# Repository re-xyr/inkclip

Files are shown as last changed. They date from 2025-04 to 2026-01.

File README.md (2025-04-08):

# Inkclip

Inkclip is an e-paper hair clip.

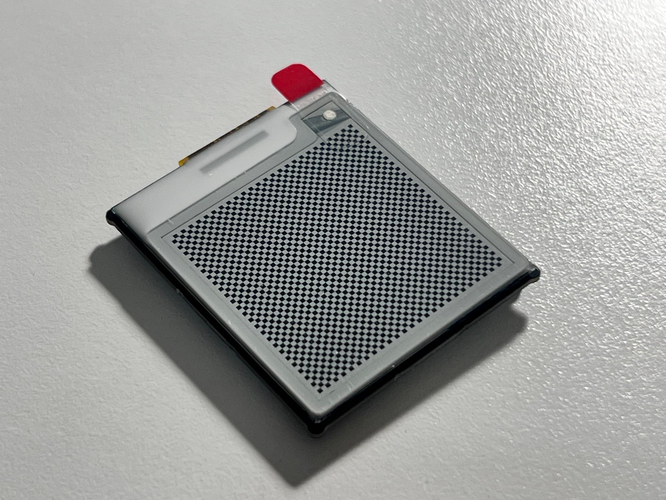
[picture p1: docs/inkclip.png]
An Inkclip lying on a desk.


## Features

- It looks cool, if you are the type of person who thinks this kind of things look cool.
- Use it as more than a hair clip: a pin, a pocket clip, or just a gadget on your desktop.
- Update the pattern on the hair clip by simply connecting it to a computer via USB.
  - There is a ready-made web application you can use for this!
- Everything is open source: the hardware, the firmware, and the webapp.

## Physical characteristics

- Display size: 1.54 inches
- Resolution: 200 x 200 px
- Color: black and white
- Thickness (average): 2.60mm
- Thickness (thickest): 5.00mm (at micro-B port)
- Minimum weight (without mounting hardware): 6.5g
- Typical weight (with a 35mm hair clip): 8.0g
- Size: 33.40mm x 33.92mm
  - The shape of the device is a 32.80mm x 38.32mm rectangle with 1mm-radius dogbone corners.

## Project structure

- `hardware/` is the KiCad project for the Inkclip hardware.
- `firmware/` is a simple firmware for Inkclip that receives image bitmaps and then updates the entire display.
- `webapp/` is a web application for updating the display that works with the aforementioned firmware.

## Demo

A demo of an Inkclip refreshing its display.

## License

The hardware design portion of this project is available under the *CERN Open Hardware Licence Version 2 - Strongly Reciprocal (`CERN-OHL-S-2.0`)* while the software portion is available under the *GNU General Public License v3.0 or later (`GPL-3.0-or-later`)*. For details, refer to the `LICENSE` files under each subdirectory of this repository.

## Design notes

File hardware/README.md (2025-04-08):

# PCB design files of Inkclip

This is the [KiCad](https://www.kicad.org/) project for the PCB design of Inkclip. This PCB is designed to work with [Waveshare's 1.54-inch e-paper](https://www.waveshare.com/product/1.54inch-e-paper.htm).

The shape of the PCB is a 32.80 x 38.32mm rectangle with 1mm-radius dogbone corners. This ensures 0.5mm clearance from the PCB edge to the e-paper everywhere along the edges. Approximately in the middle of the PCB there is a 7.5mm wide horizontal component-free zone where you may attach mounting solutions of your choice (e.g. a hairclip, a pin, a pocket clip, velcro, tape, etc).

Specifically notice that the 24-pin FPC connector must be *top-contact* since the FPC cable of the display module is supposed to bend over so that the display may be mounted on the back side of the PCB. The positioning of this FPC connector is under the assumption that the PCB is 1.0mm thick, which is the thinnest [JLCPCB](https://jlcpcb.com) could print without the price going up. If you plan to print a thinner/thicker PCB then you might need to adjust the position of this connector accordingly.

This design uses an [STM32F411CEU6](https://www.st.com/en/microcontrollers-microprocessors/stm32f411ce.html) MCU. It has 512kB flash and 128kB RAM, which should be significantly more than what is needed by the firmware provided in this repository. On the bottom-right corner of the PCB there are pin holes for SWD debugging in the order [GND, SWCLK, SWDIO, 3V3]. The pushbutton on the PCB pulls BOOT0 up, which brings the MCU into DFU mode where you can write firmware over USB.

## License

The hardware design of Inkclip, namely all files under this directory, is provided under [CERN Open Hardware License Version 2 - Strongly Reciprocal (`CERN-OHL-S-2.0`)](LICENSE).

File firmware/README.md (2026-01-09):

# Inkclip Firmware

> WARNING! Contents below are outdated; we are currently using a USB MIDI-based firmware for better cross-platform compatibility.

This is the firmware implementation for Inkclip. It implements a USB 2.0 HID device with the following reports:

- **Write Pattern:** Report ID = 0x01, Direction = Output (host to device), Size = 5,000 bytes.

  Updates the pattern on the e-paper display of the device. The 5,000 bytes are interpreted as a 40,000-bit bit vector that represents a bitmap of the 200x200 pattern to be displayed. Each byte is the little-endian representation of 8 pixels on the display, from left to right, from top to bottom, in row-major order.

  Namely, the `k`th least significant bit in the `n`th byte of the report represents the pixel value at coordinates `(x, y) = (n % 25 + k, n / 25)`.

- **Serial Number Request:** Report ID = 0x02, Direction = Output (host to device), Size = 1 byte.

  Sends a request for the device's unique serial number. The content of the 1-byte payload is ignored.

- **Serial Number Response:** Report ID = 0x02, Direction = Input (device to host), Size = 16 bytes.

  An ASCII representation of the device's unique serial number. Currently, this is implemented as the base-64 encoding of the 12-byte UID of the STM32 MCU.

## Flashing the Firmware

If you simply want to flash the firmware onto a completed Inkclip device, you can use the [cargo-dfu](https://github.com/dfu-rs/cargo-dfu) tool. Simply connect the device via USB with BOOT0 pulled up and then run under this directory

```sh
cargo dfu --release
```

If you want to debug this firmware through e.g. [SWD](https://developer.arm.com/documentation/100893/latest/Debug-and-trace-interface/Serial-Wire-Debug-signals) then you can use [probe-rs](https://probe.rs/) with a debugging probe instead.

## Implementation Details

- The USB device sets the maximum current to 100mA, which should be well above the active power draw of the actual hardware (9mA MCU + 8mA e-paper).
- The SPI link between the MCU and the e-paper display is 20MHz, which is the maximum supported frequency listed on the display module's datasheet.
- This firmware is implemented in no_std Rust with the [embassy](https://embassy.dev) framework and the [embassy-stm32](https://docs.embassy.dev/embassy-stm32/git/stm32f411ce/index.html) HAL.

## License

This firmware implementation for Inkclip, namely all files under this directory, is provided under [GNU General Public License v3.0 or later (`GPL-3.0-or-later`)](LICENSE).

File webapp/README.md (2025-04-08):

# Write to Inkclip

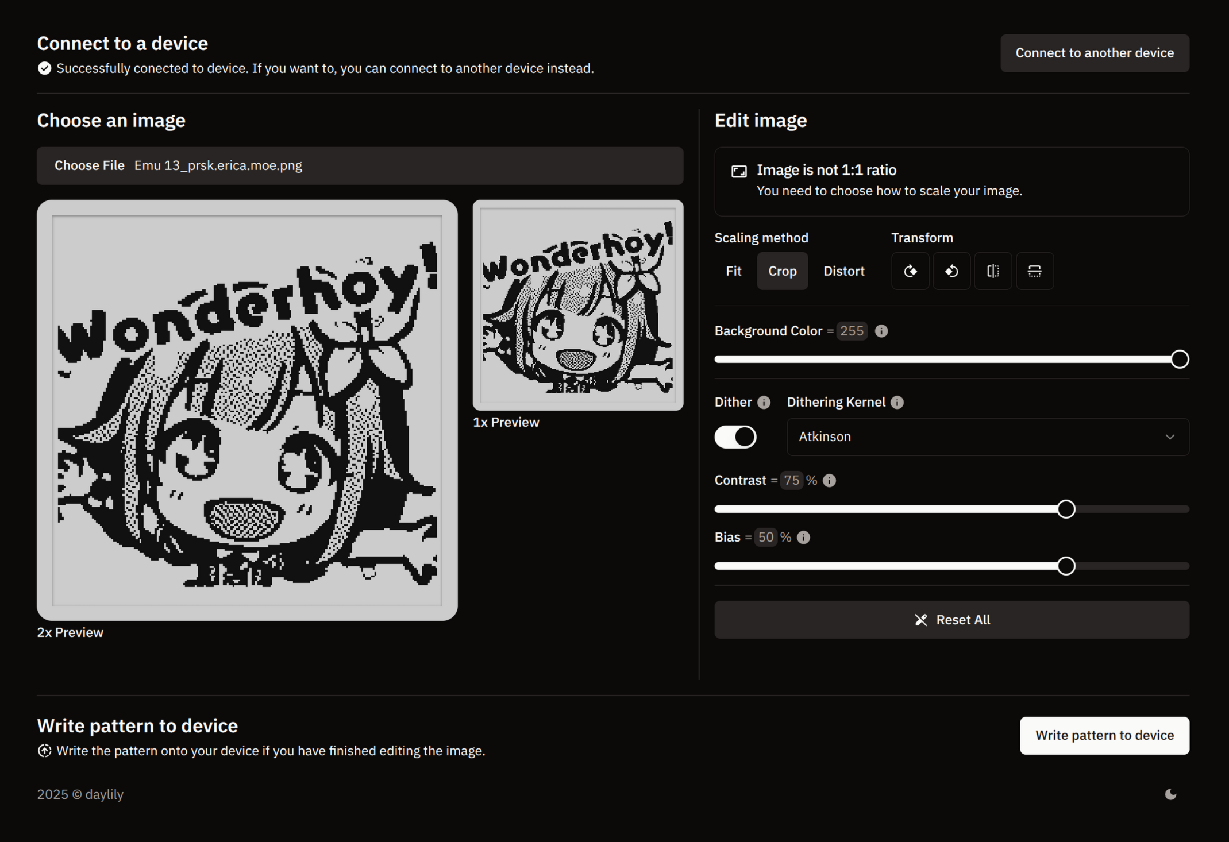
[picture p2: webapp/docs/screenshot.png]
A screenshot of the Write to Inkclip web app.


Write to Inkclip is a web application for writing patterns onto the Inkclip device. It handles the conversion from any raster image format supported by the user's web browser into a format that is understood by the Inkclip firmware, and then sends this data to the connected Inkclip via WebHID.

This application also supports some primitive image editing functions, such as scaling and cropping, rotation and mirroring, the adjustment of contrast and brightness, and a range of dithering algorithms available to use for converting images to black-and-white.

## Building

Run `npm run dev` under this directory in order to spin up a Vite development server, and run `npm run build` to bundle the application.

## Technical matters

Write to Inkclip depends on the [WebHID API](https://developer.mozilla.org/en-US/docs/Web/API/WebHID_API) to send data to devices. As a consequence, it is only supported on Chromium-based browsers, which are the only browsers that support WebHID at this time.

Write to Inkclip is a fully client-side application. It is built with [Svelte](https://svelte.dev), [shadcn-svelte](https://next.shadcn-svelte.com), [Vite](https://vite.dev), and [Tailwind CSS](https://tailwindcss.com). An instance of Write to Inkclip is hosted at https://inkclip.dayli.ly.

## License

The Write to Inkclip web application, namely all files under this directory, is provided under [GNU General Public License v3.0 or later (`GPL-3.0-or-later`)](LICENSE).

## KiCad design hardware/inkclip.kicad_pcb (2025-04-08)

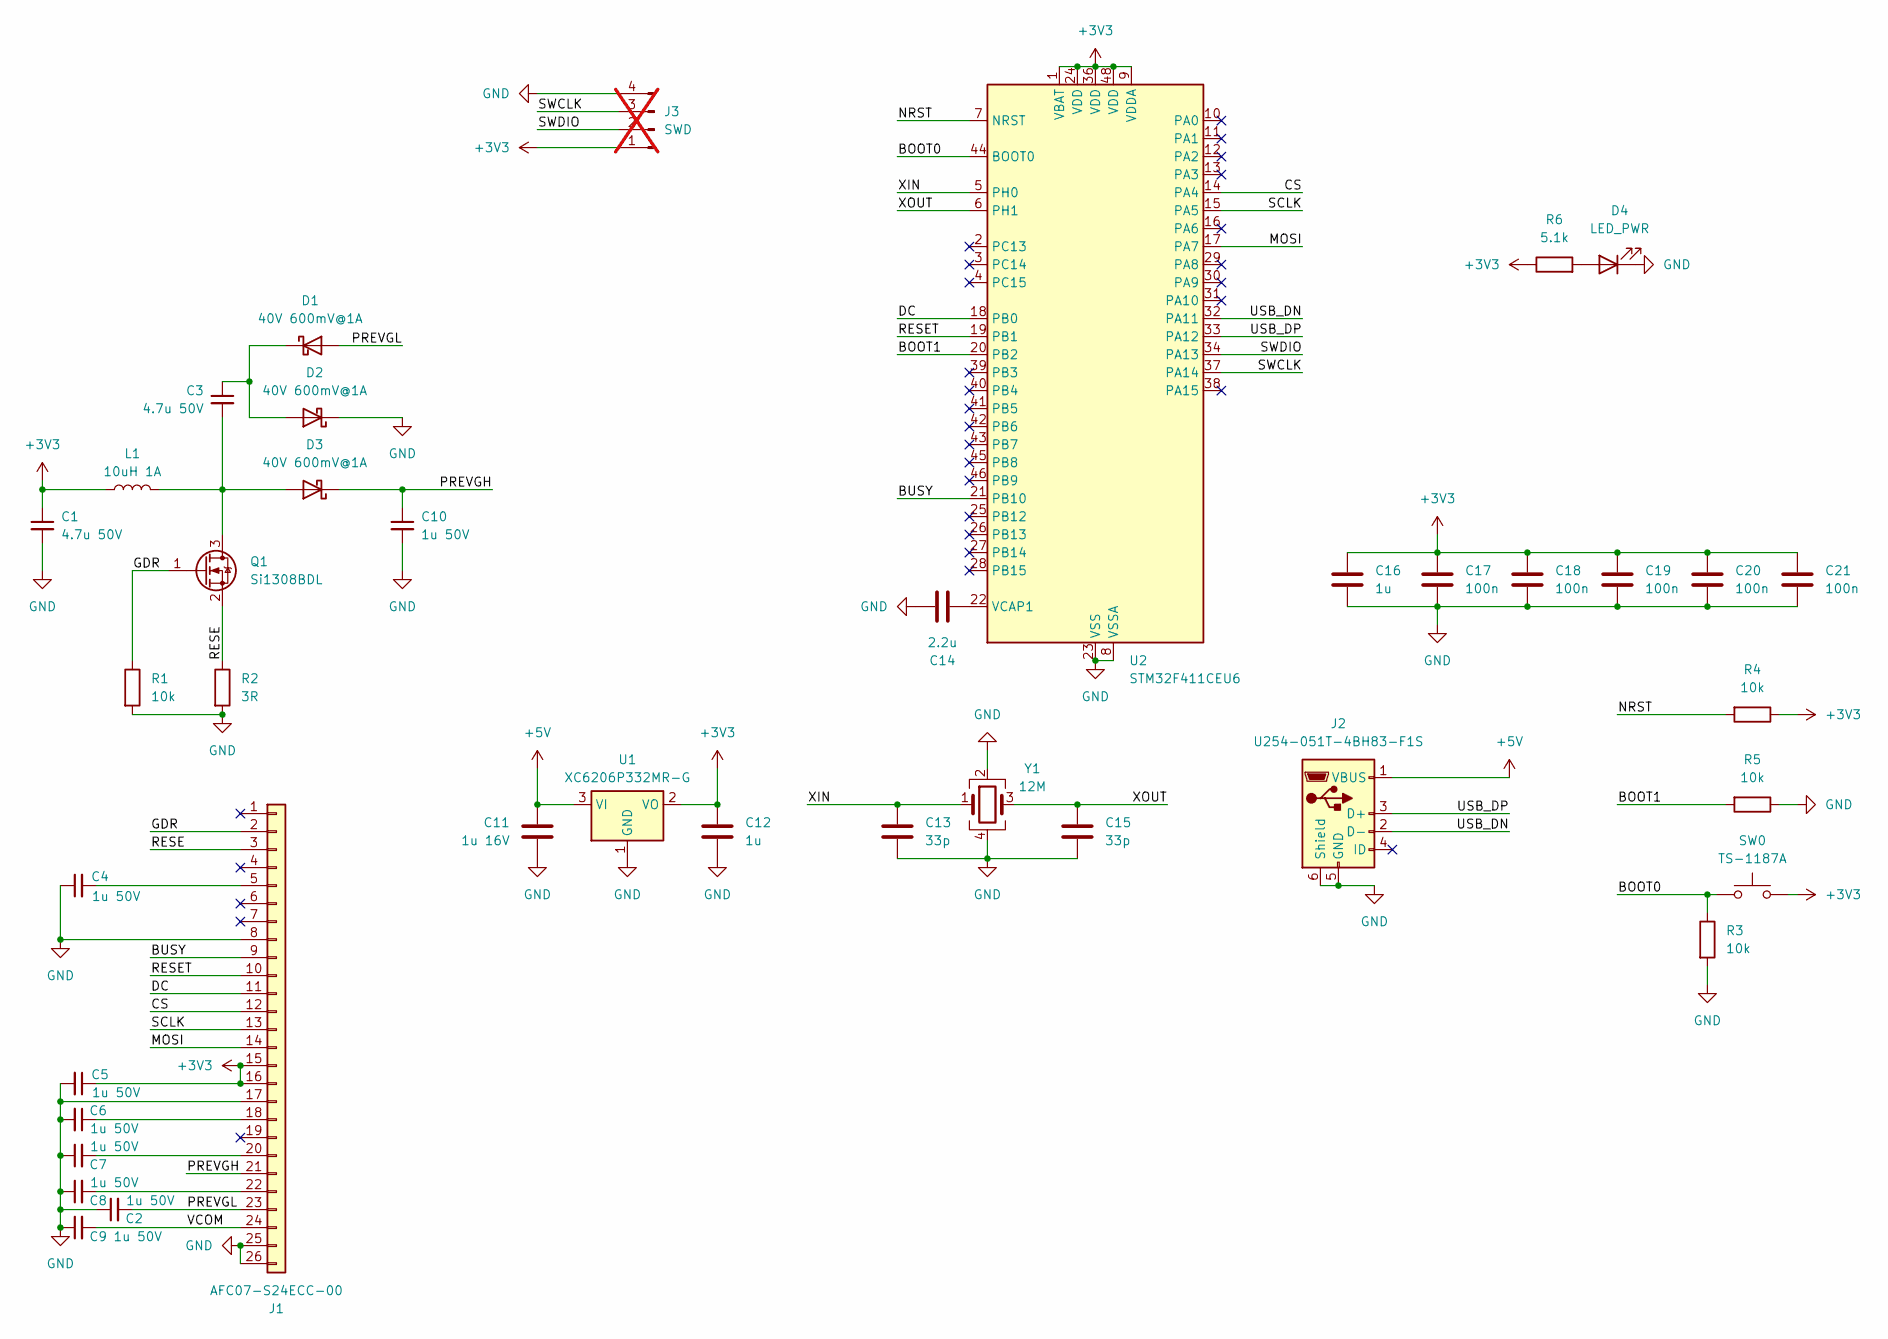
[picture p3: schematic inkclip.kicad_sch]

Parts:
C1, C3: 4.7u 50V; C_1206_3216Metric
C2, C4, C5, C6, C7, C8, C9, C10: 1u 50V; C_0603_1608Metric
C11: 1u 16V; C_0402_1005Metric
C12, C16: 1u; C_0402_1005Metric
C13, C15: 33p; C_0402_1005Metric
C14: 2.2u; C_0402_1005Metric
C17, C18, C19, C20, C21: 100n; C_0402_1005Metric
D1, D2, D3: 40V 600mV@1A; D_SOD-323
D4: LED_PWR; LED_0603_1608Metric
J1: AFC07-S24ECC-00; FPC-SMD_24P-L17.5-W5.4-P0.50
J2: U254-051T-4BH83-F1S; USB_Micro-B_XKB_U254-051T-4BH83-F1S
J3: SWD; PinHeader_1x04_P2.54mm_Vertical; not fitted
L1: 10uH 1A; L_Changjiang_FNR4018S
Q1: Si1308BDL; SOT-323_SC-70
R1, R3, R4, R5: 10k; R_0402_1005Metric
R2: 3R; R_0402_1005Metric
R6: 5.1k; R_0402_1005Metric
SW0: TS-1187A; SW_Push_1P1T_XKB_TS-1187A
U1: XC6206P332MR-G; SOT-23-3
U2: STM32F411CEU6; QFN-48-1EP_7x7mm_P0.5mm_EP5.6x5.6mm
Y1: 12M; Crystal_SMD_3225-4Pin_3.2x2.5mm

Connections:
+3V3: C1.1, C5.1, C12.1, C16.1, C17.1, C18.1, C19.1, C20.1, C21.1, J1.15, J1.16, J3.1, L1.1, R4.1, R6.1, SW0.2, U1.2 (VO), U2.1 (VBAT), U2.9 (VDDA), U2.24 (VDD), U2.36 (VDD), U2.48 (VDD)
+5V: C11.1, J2.1 (VBUS), U1.3 (VI)
/BOOT0: R3.1, SW0.1, U2.44 (BOOT0)
/BOOT1: R5.2, U2.20 (PB2)
/BUSY: J1.9, U2.21 (PB10)
/CS: J1.12, U2.14 (PA4)
/DC: J1.11, U2.18 (PB0)
/GDR: J1.2, Q1.1 (G), R1.1
/LED: U2.25 (PB12)
/MOSI: J1.14, U2.17 (PA7)
/NRST: R4.2, U2.7 (NRST)
/PREVGH: C10.1, D3.1 (K), J1.21
/PREVGL: C2.2, D1.2 (A), J1.23
/RESE: J1.3, Q1.2 (S), R2.1
/RESET: J1.10, U2.19 (PB1)
/SCLK: J1.13, U2.15 (PA5)
/SWCLK: J3.3, U2.37 (PA14)
/SWDIO: J3.2, U2.34 (PA13)
/USB_DN: J2.2 (D-), U2.32 (PA11)
/USB_DP: J2.3 (D+), U2.33 (PA12)
/VCOM: C9.2, J1.24
/XIN: C13.1, U2.5 (PH0), Y1.1
/XOUT: C15.1, U2.6 (PH1), Y1.3
GND: C1.2, C2.1, C4.1, C5.2, C6.2, C7.1, C8.1, C9.1, C10.2, C11.2, C12.2, C13.2, C14.1, C15.2, C16.2, C17.2, C18.2, C19.2, C20.2, C21.2, D2.1 (K), D4.1 (K), J1.8, J1.17, J1.25, J1.26, J2.5 (GND), J2.6 (Shield), J3.4, R1.2, R2.2, R3.2, R5.1, U1.1 (GND), U2.8 (VSSA), U2.23 (VSS), U2.35 (VSS), U2.47 (VSS), U2.49 (VSS), Y1.2, Y1.4
unnamed: C3.1, D1.1 (K), D2.2 (A)
unnamed: C3.2, D3.2 (A), L1.2, Q1.3 (D)
unnamed: D4.2 (A), R6.2
unnamed: C4.2, J1.5
unnamed: C6.1, J1.18
unnamed: C7.2, J1.20
unnamed: C8.2, J1.22
unnamed: C14.2, U2.22 (VCAP1)

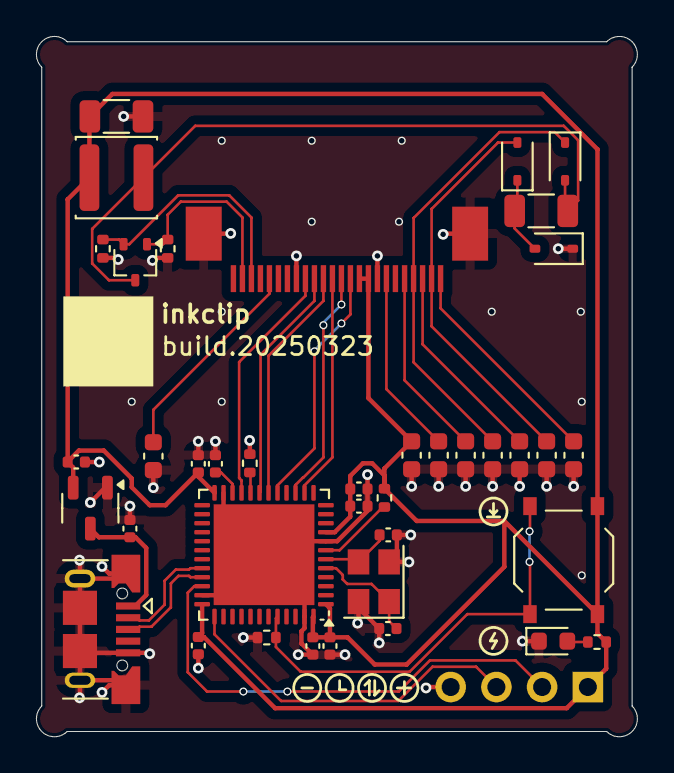
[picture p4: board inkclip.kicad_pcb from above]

Board: 2 copper layers, 33.4 x 38.9 mm, 40 parts (1 on the bottom side), 31 nets.

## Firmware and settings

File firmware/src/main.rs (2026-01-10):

#![no_main]
#![no_std]

use crate::{
    app::app_task,
    epd::Epd,
    midi::{make_midi_class, make_usb_builder, usb_task},
};

use defmt_rtt as _;
use embassy_executor::{Spawner, main};
use embassy_stm32::{
    Peripherals, bind_interrupts,
    peripherals::USB_OTG_FS,
    time::Hertz,
    usb::{self},
};
#[cfg(not(debug_assertions))]
use panic_abort as _;
#[cfg(debug_assertions)]
use panic_probe as _;

macro_rules! static_ref {
    ($ty:ty = $expr:expr) => {{
        static CELL: static_cell::StaticCell<$ty> = StaticCell::new();
        CELL.init($expr)
    }};
}

mod app;
mod epd;
mod midi;
mod pack;
mod sysex;
mod uid;

bind_interrupts!(pub struct Irqs {
  OTG_FS => usb::InterruptHandler<USB_OTG_FS>;
});

fn init_peripherals() -> Peripherals {
    embassy_stm32::init({
        use embassy_stm32::rcc::*;
        let mut config = embassy_stm32::Config::default();

        config.rcc.hse = Some(Hse {
            freq: Hertz(12_000_000),
            mode: HseMode::Oscillator,
        });
        config.rcc.pll_src = PllSource::HSE;
        config.rcc.pll = Some(Pll {
            prediv: PllPreDiv::DIV12,  // 12 / 12 = 1 MHz
            mul: PllMul::MUL192,       // 1 * 192 = 192 MHz
            divp: Some(PllPDiv::DIV2), // 192 / 2 = 96 MHz <= 100 MHz max freq
            divq: Some(PllQDiv::DIV4), // 192 / 4 = 48 MHz necessary for USB
            divr: None,
        });
        config.rcc.ahb_pre = AHBPrescaler::DIV1;
        config.rcc.apb1_pre = APBPrescaler::DIV2;
        config.rcc.apb2_pre = APBPrescaler::DIV4;
        config.rcc.sys = Sysclk::PLL1_P;
        config.rcc.mux.clk48sel = mux::Clk48sel::PLL1_Q;

        config
    })
}

#[main]
async fn main(spawner: Spawner) {
    let peri = init_peripherals();
    let epd = Epd::new(
        peri.SPI1, peri.PA4, peri.PA5, peri.PA7, peri.PB10, peri.PB0, peri.PB1,
    );

    let mut usb_builder = make_usb_builder(peri.USB_OTG_FS, peri.PA12, peri.PA11).await;
    let midi = make_midi_class(&mut usb_builder);

    spawner.must_spawn(usb_task(usb_builder));
    spawner.must_spawn(app_task(epd, midi));
}

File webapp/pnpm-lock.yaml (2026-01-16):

lockfileVersion: '9.0'

settings:
  autoInstallPeers: true
  excludeLinksFromLockfile: false

importers:

  .:
    devDependencies:
      '@ianvs/prettier-plugin-sort-imports':
        specifier: ^4.7.0
        version: 4.7.0(prettier@3.7.4)
      '@iconify/json':
        specifier: ^2.2.428
        version: 2.2.428
      '@internationalized/date':
        specifier: ^3.10.1
        version: 3.10.1
      '@lucide/svelte':
        specifier: ^0.562.0
        version: 0.562.0(svelte@5.46.3)
      '@sveltejs/vite-plugin-svelte':
        specifier: ^6.2.4
        version: 6.2.4(svelte@5.46.3)(vite@7.3.1(@types/node@24.10.8)(jiti@2.6.1)(lightningcss@1.30.2)(terser@5.44.1))
      '@tailwindcss/vite':
        specifier: ^4.1.18
        version: 4.1.18(vite@7.3.1(@types/node@24.10.8)(jiti@2.6.1)(lightningcss@1.30.2)(terser@5.44.1))
      '@tsconfig/svelte':
        specifier: ^5.0.6
        version: 5.0.6
      '@types/node':
        specifier: ^24.10.8
        version: 24.10.8
      '@types/w3c-web-hid':
        specifier: ^1.0.6
        version: 1.0.6
      '@variegated-coffee/serde-postcard-ts':
        specifier: ^0.1.4
        version: 0.1.4
      '@vite-pwa/assets-generator':
        specifier: ^1.0.2
        version: 1.0.2
      autoprefixer:
        specifier: ^10.4.23
        version: 10.4.23(postcss@8.5.6)
      bits-ui:
        specifier: ^2.15.4
        version: 2.15.4(@internationalized/date@3.10.1)(svelte@5.46.3)
      clsx:
        specifier: ^2.1.1
        version: 2.1.1
      mode-watcher:
        specifier: ^1.1.0
        version: 1.1.0(svelte@5.46.3)
      prettier:
        specifier: ^3.7.4
        version: 3.7.4
      prettier-plugin-svelte:
        specifier: ^3.4.1
        version: 3.4.1(prettier@3.7.4)(svelte@5.46.3)
      prettier-plugin-tailwindcss:
        specifier: ^0.7.2
        version: 0.7.2(@ianvs/prettier-plugin-sort-imports@4.7.0(prettier@3.7.4))(prettier-plugin-svelte@3.4.1(prettier@3.7.4)(svelte@5.46.3))(prettier@3.7.4)
      svelte:
        specifier: ^5.46.3
        version: 5.46.3
      svelte-sonner:
        specifier: ^1.0.7
        version: 1.0.7(svelte@5.46.3)
      tailwind-merge:
        specifier: ^3.4.0
        version: 3.4.0
      tailwind-variants:
        specifier: ^3.2.2
        version: 3.2.2(tailwind-merge@3.4.0)(tailwindcss@4.1.18)
      tailwindcss:
        specifier: ^4.1.18
        version: 4.1.18
      tw-animate-css:
        specifier: ^1.4.0
        version: 1.4.0
      typescript:
        specifier: ^5.9.3
        version: 5.9.3
      unplugin-icons:
        specifier: ^23.0.1
        version: 23.0.1(svelte@5.46.3)
      vite:
        specifier: ^7.3.1
        version: 7.3.1(@types/node@24.10.8)(jiti@2.6.1)(lightningcss@1.30.2)(terser@5.44.1)
      vite-plugin-pwa:
        specifier: ^1.2.0
        version: 1.2.0(@vite-pwa/assets-generator@1.0.2)(vite@7.3.1(@types/node@24.10.8)(jiti@2.6.1)(lightningcss@1.30.2)(terser@5.44.1))(workbox-build@7.4.0)(workbox-window@7.4.0)
      workbox-window:
        specifier: ^7.4.0
        version: 7.4.0
      wrangler:
        specifier: ^4.59.1
        version: 4.59.1

packages:

  '@antfu/install-pkg@1.1.0':
    resolution: {integrity: sha512-MGQsmw10ZyI+EJo45CdSER4zEb+p31LpDAFp2Z3gkSd1yqVZGi0Ebx++YTEMonJy4oChEMLsxZ64j8FH6sSqtQ==}

  '@apideck/better-ajv-errors@0.3.6':
    resolution: {integrity: sha512-P+ZygBLZtkp0qqOAJJVX4oX/sFo5JR3eBWwwuqHHhK0GIgQOKWrAfiAaWX0aArHkRWHMuggFEgAZNxVPwPZYaA==}
    engines: {node: '>=10'}
    peerDependencies:
      ajv: '>=8'

  '@babel/code-frame@7.28.6':
    resolution: {integrity: sha512-JYgintcMjRiCvS8mMECzaEn+m3PfoQiyqukOMCCVQtoJGYJw8j/8LBJEiqkHLkfwCcs74E3pbAUFNg7d9VNJ+Q==}
    engines: {node: '>=6.9.0'}

  '@babel/compat-data@7.28.6':
    resolution: {integrity: sha512-2lfu57JtzctfIrcGMz992hyLlByuzgIk58+hhGCxjKZ3rWI82NnVLjXcaTqkI2NvlcvOskZaiZ5kjUALo3Lpxg==}
    engines: {node: '>=6.9.0'}

  '@babel/core@7.28.6':
    resolution: {integrity: sha512-H3mcG6ZDLTlYfaSNi0iOKkigqMFvkTKlGUYlD8GW7nNOYRrevuA46iTypPyv+06V3fEmvvazfntkBU34L0azAw==}
    engines: {node: '>=6.9.0'}

  '@babel/generator@7.28.6':
    resolution: {integrity: sha512-lOoVRwADj8hjf7al89tvQ2a1lf53Z+7tiXMgpZJL3maQPDxh0DgLMN62B2MKUOFcoodBHLMbDM6WAbKgNy5Suw==}
    engines: {node: '>=6.9.0'}

  '@babel/helper-annotate-as-pure@7.27.3':
    resolution: {integrity: sha512-fXSwMQqitTGeHLBC08Eq5yXz2m37E4pJX1qAU1+2cNedz/ifv/bVXft90VeSav5nFO61EcNgwr0aJxbyPaWBPg==}
    engines: {node: '>=6.9.0'}

  '@babel/helper-compilation-targets@7.28.6':
    resolution: {integrity: sha512-JYtls3hqi15fcx5GaSNL7SCTJ2MNmjrkHXg4FSpOA/grxK8KwyZ5bubHsCq8FXCkua6xhuaaBit+3b7+VZRfcA==}
    engines: {node: '>=6.9.0'}

  '@babel/helper-create-class-features-plugin@7.28.6':
    resolution: {integrity: sha512-dTOdvsjnG3xNT9Y0AUg1wAl38y+4Rl4sf9caSQZOXdNqVn+H+HbbJ4IyyHaIqNR6SW9oJpA/RuRjsjCw2IdIow==}
    engines: {node: '>=6.9.0'}
    peerDependencies:
      '@babel/core': ^7.0.0
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

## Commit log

2025-04-04 Remove extraneous prop
2025-04-08 hardware: add hardware
    [inkclip.kicad_pcb, inkclip.kicad_sch]
2025-04-08 hardware: remove draft Edge.Cuts
    [inkclip.kicad_pcb]
2026-01-09 Fix a panic when checking for magic number in firmware
    [app.rs]
2026-01-09 Move DeviceType to first position in GetIdentification
2026-01-10 Reduce and calibrate RAM usage in firmware
2026-01-10 Fix a small calculation error for buffer size
    [app.rs]
2026-01-12 Fix screen rotation in firmware
    [app.rs]
2026-01-16 Add some flow guidance in the form of title opacity/weight changes
